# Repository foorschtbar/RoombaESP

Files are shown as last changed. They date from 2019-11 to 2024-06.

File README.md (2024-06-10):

# RoombaESP

This project is a Add-On PCB for the Roomba vacuum cleaner robots of series 500/600/700. It uses the open interface of the Roomba to control the robot via a ESP8266 microcontroller. The PCB is designed to be mounted on top in a 3D printed case and add

- MQTT
- REST API
- Monitoring Interface
- OLED Screen
- Status LED

## PCB

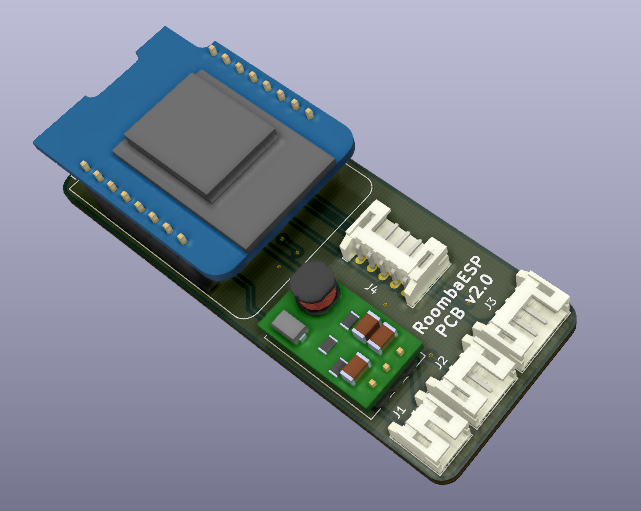
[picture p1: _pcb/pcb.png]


## Case & Features

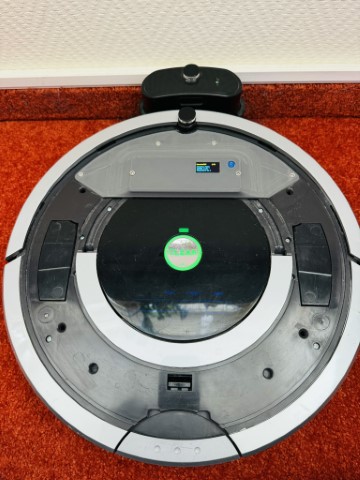
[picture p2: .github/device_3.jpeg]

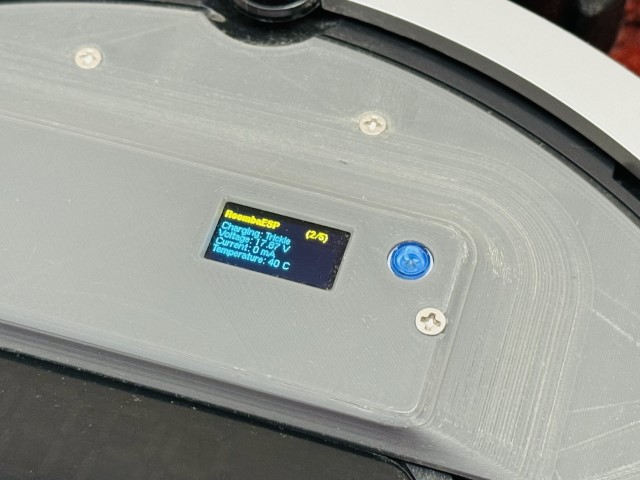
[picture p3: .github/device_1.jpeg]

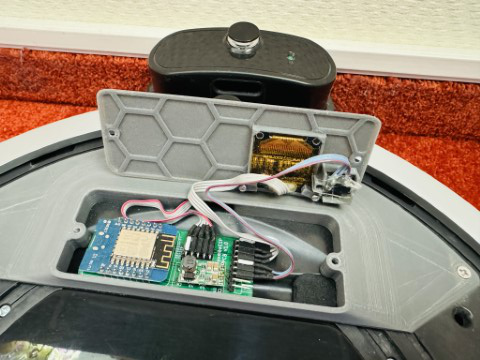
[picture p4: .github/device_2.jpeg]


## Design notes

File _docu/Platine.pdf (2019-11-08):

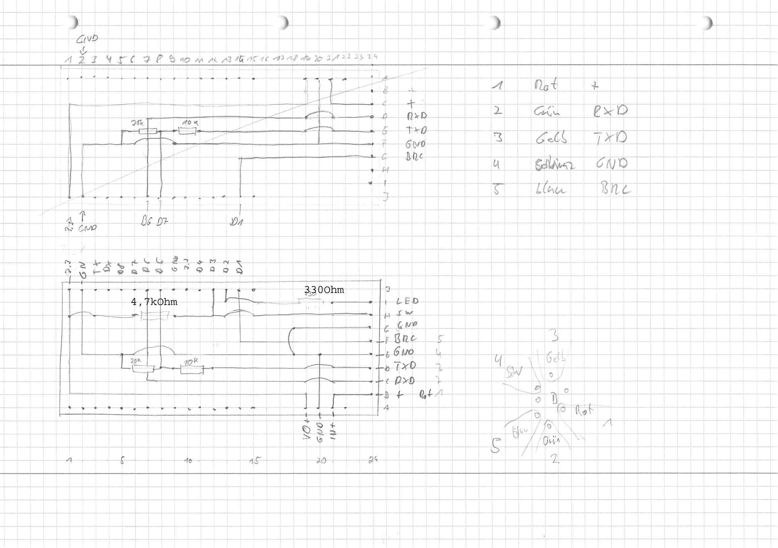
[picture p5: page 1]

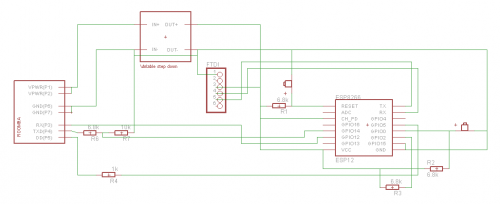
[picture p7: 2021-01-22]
_docu/R4_Circuit_Diag.png

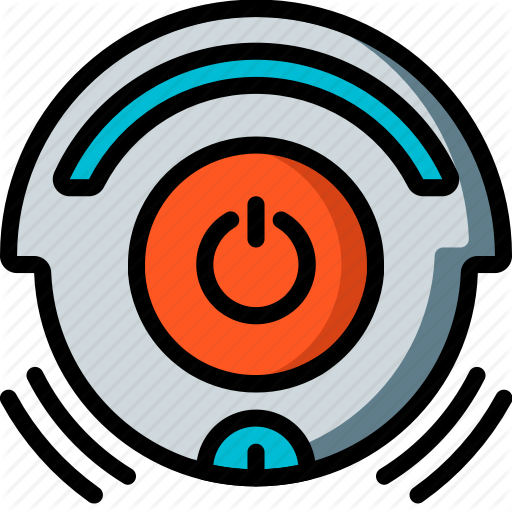
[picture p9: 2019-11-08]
_docu/Home_Automation_-_Ultra_-_049_-_Roomba_Off-512.png

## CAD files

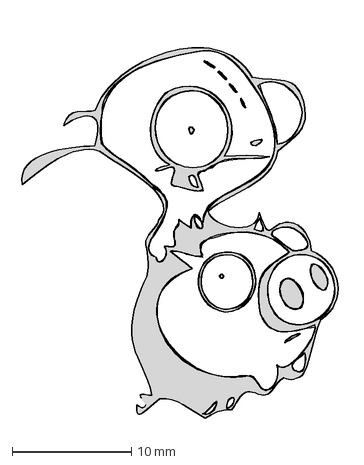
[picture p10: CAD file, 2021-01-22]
_pcb/invader zim flying pig_512.dxf
27.8 x 34.3 mm

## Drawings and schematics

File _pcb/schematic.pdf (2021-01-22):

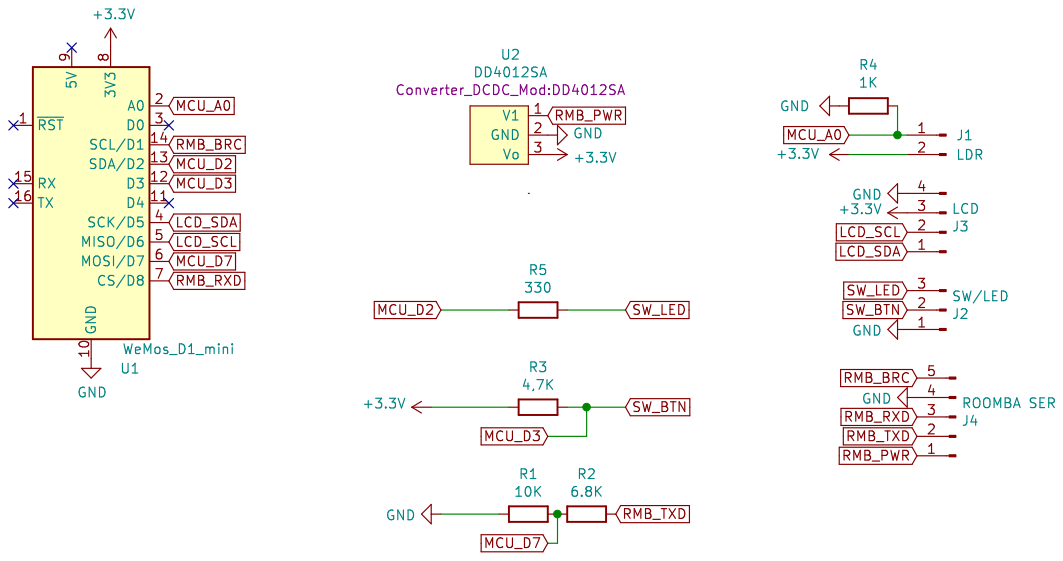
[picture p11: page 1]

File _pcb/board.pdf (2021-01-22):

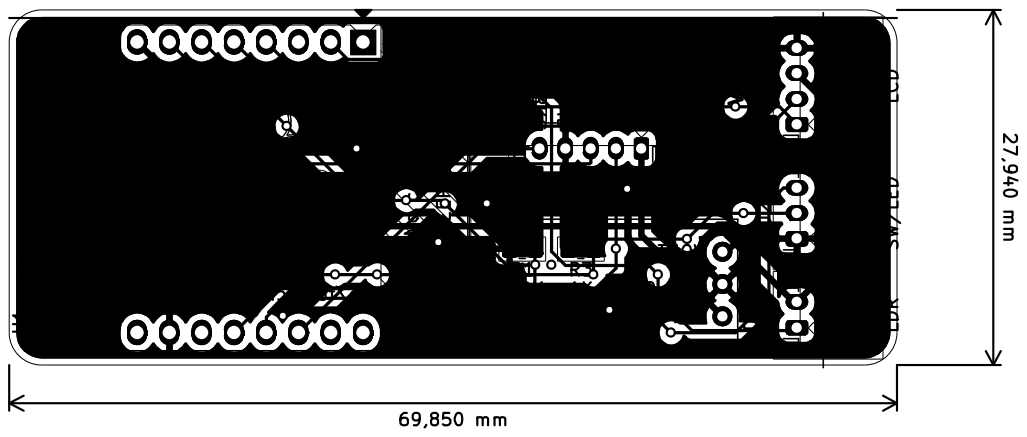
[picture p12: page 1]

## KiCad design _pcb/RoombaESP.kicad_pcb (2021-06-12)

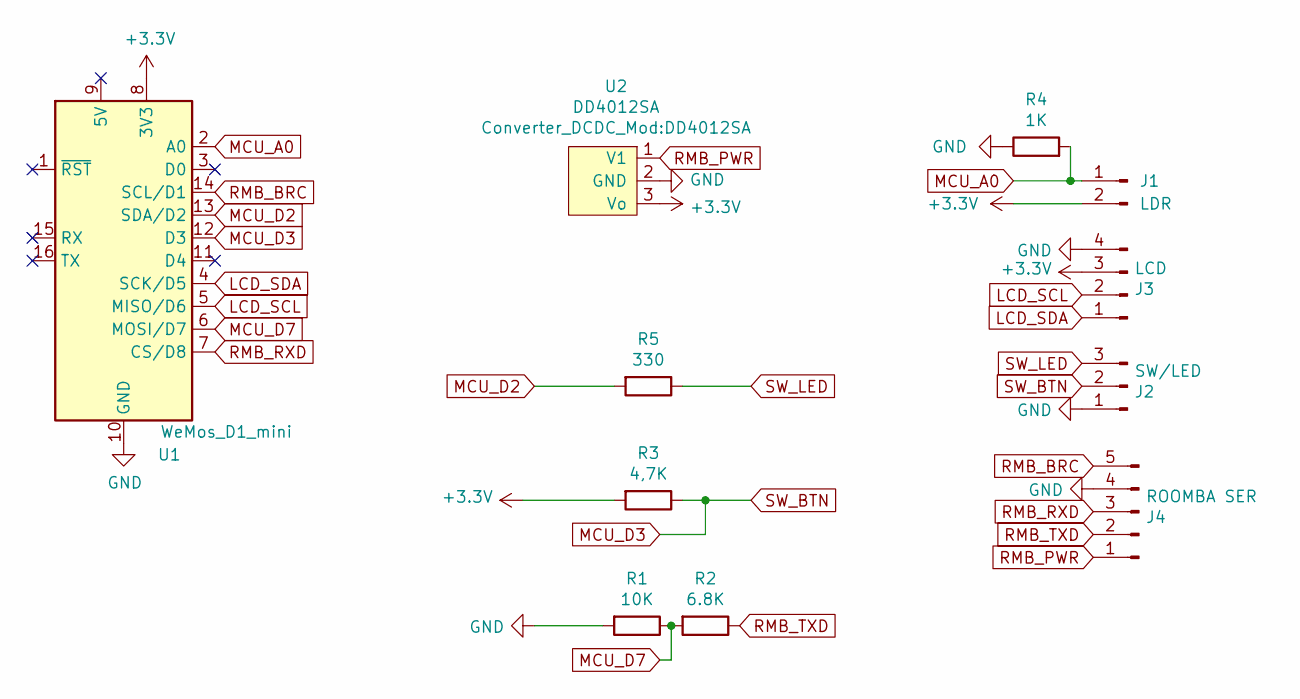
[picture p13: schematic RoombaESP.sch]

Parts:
J1: LDR; JST_PH_S2B-PH-K_1x02_P2.00mm_Horizontal
J2: SW/LED; JST_PH_S3B-PH-K_1x03_P2.00mm_Horizontal
J3: LCD; JST_PH_S4B-PH-K_1x04_P2.00mm_Horizontal
J4: ROOMBA SER; JST_PH_S5B-PH-K_1x05_P2.00mm_Horizontal
R1: 10K; R_0805_2012Metric_Pad1.20x1.40mm_HandSolder
R2: 6.8K; R_0805_2012Metric_Pad1.20x1.40mm_HandSolder
R3: 4,7K; R_0805_2012Metric_Pad1.20x1.40mm_HandSolder
R4: 1K; R_0805_2012Metric_Pad1.20x1.40mm_HandSolder
R5: 330; R_0805_2012Metric_Pad1.20x1.40mm_HandSolder
U1: WeMos_D1_mini; WEMOS_D1_mini_light
U2: DD4012SA

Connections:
+3V3: J1.2, J3.3, R3.2, U1.8 (3V3), U2.3 (Vo)
GND: J2.1, J3.4, J4.4, R1.2, R4.1, U1.10 (GND), U2.2 (GND)
LCD_SCL: J3.2, U1.5 (MISO/D6)
LCD_SDA: J3.1, U1.4 (SCK/D5)
MCU_A0: J1.1, R4.2, U1.2 (A0)
MCU_D2: R5.2, U1.13 (SDA/D2)
MCU_D3: J2.2, R3.1, U1.12 (D3)
MCU_D7: R1.1, R2.2, U1.6 (MOSI/D7)
RMB_BRC: J4.5, U1.14 (SCL/D1)
RMB_PWR: J4.1, U2.1 (V1)
RMB_RXD: J4.3, U1.7 (CS/D8)
RMB_TXD: J4.2, R2.1
SW_LED: J2.3, R5.1

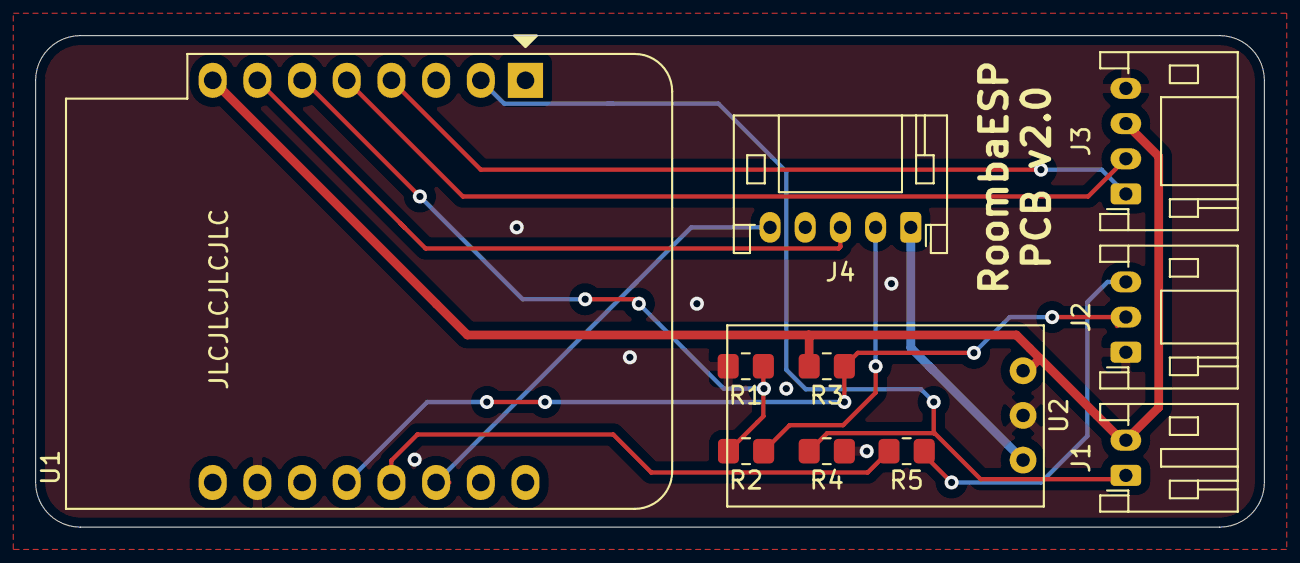
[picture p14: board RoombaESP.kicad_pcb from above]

Board: 2 copper layers, 69.9 x 27.9 mm, 11 parts (0 on the bottom side), 13 nets.

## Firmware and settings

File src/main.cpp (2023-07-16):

// Remote debug over telnet - not recommended for production, only for development
#include <RemoteDebug.h> //https://github.com/JoaoLopesF/RemoteDebug
#include <NTPClient.h>
#include <WiFiUdp.h> // needed by NTPClient.h
#include <ESP8266WiFi.h>
#include <WiFiClient.h>
#include <PubSubClient.h> // API Doc: https://pubsubclient.knolleary.net/api.html
#include <ArduinoJson.h>  // API Doc: https://arduinojson.org/v6/doc/
#include <ESP8266WebServer.h>
#include <ESP8266HTTPUpdateServer.h>
#include <EEPROM.h>
#include <U8g2lib.h>
#include <Wire.h>
#include <jled.h>
#include <Ticker.h>
#include <settings.h> // Include my type definitions (must be in a separate file!)
#include "screens.h"

// ++++++++++++++++++++++++++++++++++++++++
//
// DOCU
//
// ++++++++++++++++++++++++++++++++++++++++
/*
Serial (Swap)
http://arduino.esp8266.com/Arduino/versions/2.1.0-rc2/doc/reference.html#serial

https://dirtypcbs.com/store/designer/details/8372/892/roomba-4-zip

u8g2reference
https://github.com/olikraus/u8g2/wiki/u8g2reference
*/

// ++++++++++++++++++++++++++++++++++++++++
//
// CONSTANTS
//
// ++++++++++++++++++++++++++++++++++++++++

// Constants - HW pins
#define PIN_LED_WIFI D2 // Blue/Wifi LED (LED_BUILTIN=Nodemcu, D2 extern, D4=ESP-Chip-LED)
#define PIN_BRC D1
#define PIN_BUTTON D3

// Constants - Misc
const char FIRMWARE_VERSION[] = "2.2";
const char COMPILE_DATE[] = __DATE__ " " __TIME__;
const int PWMRANGE = 1023;

// Constants - Sensor
#define SENSORBYTES_LENGHT 10
unsigned long lastSensorStatusTime = 0;
char sensorbytes[SENSORBYTES_LENGHT];
boolean sensorbytesvalid = false;
#define CHARGE_STATE (int)(sensorbytes[0])
#define VOLTAGE (int)((sensorbytes[1] << 8) + sensorbytes[2])
#define CURRENT (signed short int)((sensorbytes[3] << 8) + sensorbytes[4])
#define TEMP (int)(sensorbytes[5])
#define CHARGE (int)((sensorbytes[6] << 8) + sensorbytes[7])
#define CAPACITY (int)((sensorbytes[8] << 8) + sensorbytes[9])

// Constants - Intervals (all in ms)
const int LED_FANCY_DURATION = 50; // interval at which to blink (milliseconds)
const int LED_WEB_MIN_TIME = 300;  // interval at which to blink (milliseconds)
const int TIME_BUTTON_LONGPRESS = 10000;
const long INTERVAL_SENSOR_STATUS = 1000;
const int STATE_PUBLISH_INTERVAL = 5000;
const int MQTT_RECONNECT_INTERVAL = 2000;
const int DISPLAY_UPDATE_INTERVAL = 200;
const int DISPLAY_TIMEOUT = 4000; // time after display will go offs

// Constants - MQTT
const char MQTT_SUBSCRIBE_CMD_TOPIC1[] = "%s/cmd";               // Subscribe patter without hostname
const char MQTT_SUBSCRIBE_CMD_TOPIC2[] = "%s%s/cmd";             // Subscribe patter with hostname
const char MQTT_PUBLISH_STATUS_TOPIC[] = "%s%s/status";          // Public pattern for status (normal and LWT) with hostname
const char MQTT_LWT_MESSAGE[] = "{\"device\":\"disconnected\"}"; // LWT message
const char MQTT_DEFAULT_PREFIX[] = "roombaesp";                  // Default MQTT topic prefix

// Constants - Screen (OLED)
const int SCREEN_COUNT = 5; // number of screens

// ++++++++++++++++++++++++++++++++++++++++
//
// ENUMS
//
// ++++++++++++++++++++++++++++++++++++++++

// Variables wont change
enum class RoombaCMDs
{
  RMB_WAKE,
  RMB_START,
  RMB_STOP,
  RMB_CLEAN,
  RMB_MAX,
  RMB_SPOT,
  RMB_DOCK,
  RMB_POWER,
  RMB_RESET
};

enum class StatusTrigger
{
  PERIODIC,
  WEB,
  MQTT,
  NONE // Triggers no update
};

// ++++++++++++++++++++++++++++++++++++++++
//
// LIBS
//
// ++++++++++++++++++++++++++++++++++++++++

ESP8266WebServer server(80);
ESP8266HTTPUpdateServer httpUpdater;
RemoteDebug Debug;
WiFiUDP ntpUDP;
NTPClient timeClient(ntpUDP, "europe.pool.ntp.org", 3600, 60000);
WiFiClient espClient;
PubSubClient client(espClient);
U8G2_SSD1306_128X64_NONAME_F_HW_I2C u8g2(U8G2_R0, /* reset=*/U8X8_PIN_NONE, /* clock=*/D6, /* data=*/D5); // pin remapping with ESP8266 HW I2C
Screens screen(u8g2, SCREEN_COUNT, DISPLAY_UPDATE_INTERVAL, DISPLAY_TIMEOUT);
Ticker ledTicker;
auto led = JLed(PIN_LED_WIFI);

// ++++++++++++++++++++++++++++++++++++++++
//
// VARS
//
// ++++++++++++++++++++++++++++++++++++++++

// Config
uint8_t cfgStart = 0;         // Start address in EEPROM for structure 'cfg'
configData_t cfg;             // Instance 'cfg' is a global variable with 'configData_t' structure now
bool configIsDefault = false; // true if no valid config found in eeprom and defaults settings loaded
const int CURRENT_CONFIG_VERSION = 2;

// Variables will change
int wifiledState = HIGH;
unsigned long lastLEDTime = 0;              // will store last time LED was updated
unsigned long lastButtonTimer = 0;          // will store how long button was pressed
unsigned long mqttLastReconnectAttempt = 0; // will store last time reconnect to mqtt broker
unsigned long nextPublishTime = 0;          // will store last publish time
unsigned long lastDisplayUpdate = 0;        // will store last display update
char mqtt_prefix[50];                       // prefix fpr mqtt topic
bool previousButtonState = 1;               // will store last Button state. 1 = unpressed, 0 = pressed
bool bIsConnected = false;
bool bMQTTsending = false;
int currentScreen = 0;
bool displayPowerSaving = true;
bool stopLEDupdate = false;
int ledBrightness = PWMRANGE;

// buffers
String html;
char buff[255];
char lastClean[50] = "---"; // will store last Clean

// function prototype
void HTMLHeader(const char *section, unsigned int refresh = 0, const char *url = "/");
void MQTTpublishStatus(StatusTrigger statusTrigger);
unsigned int getSensorStatus(bool force = false);

// ++++++++++++++++++++++++++++++++++++++++
//
// EVENT HANDLER
//
// ++++++++++++++++++++++++++++++++++++++++

WiFiEventHandler mConnectHandler;
WiFiEventHandler mDisConnectHandler;

// ++++++++++++++++++++++++++++++++++++++++
//
// MAIN CODE
//
// ++++++++++++++++++++++++++++++++++++++++

void clearSerialBuffer()
{
  while (Serial.available())
  {
    Serial.read();
  }
}

void saveConfig()
{
  EEPROM.begin(512);
  EEPROM.put(cfgStart, cfg);
  delay(200);
  EEPROM.commit(); // Only needed for ESP8266 to get data written
  EEPROM.end();
}

void eraseConfig()
{
  EEPROM.begin(512);
  for (uint8_t i = cfgStart; i < sizeof(cfg); i++)
  {
    EEPROM.write(i, 0);
  }
  delay(200);
  EEPROM.commit();
  EEPROM.end();
}

void handleButton()
{
  bool inp = digitalRead(PIN_BUTTON);
  if (inp == 0)
  {
    if (inp != previousButtonState)
    {
      rdebugA("Button pressed short\n");
      // ESP.reset();
      lastButtonTimer = millis();
      screen.nextScreen();
    }
    if ((millis() - lastButtonTimer >= TIME_BUTTON_LONGPRESS))
    {
      debugA("Button pressed long\n");
      eraseConfig();
      ESP.reset();
    }

    // Delay a little bit to avoid bouncing
    delay(50);
  }
  previousButtonState = inp;
}

void roombaCmd(RoombaCMDs cmd, StatusTrigger statusTrigger = StatusTrigger::NONE)
{

  switch (cmd)
  {
  case RoombaCMDs::RMB_WAKE:
    rdebugA("%s\n", "Send RMB_WAKE to RMB");
    digitalWrite(PIN_BRC, HIGH);
    delay(50);
    digitalWrite(PIN_BRC, LOW);
    delay(50);
    digitalWrite(PIN_BRC, HIGH);
    delay(50);
    digitalWrite(PIN_BRC, LOW);
    delay(50);
    break;

  case RoombaCMDs::RMB_START:
    rdebugA("%s\n", "Send RMB_START to RMB");
    Serial.write(128); // Start
    delay(50);
    break;

  case RoombaCMDs::RMB_STOP:
    roombaCmd(RoombaCMDs::RMB_WAKE);
    rdebugA("%s\n", "Send RMB_STOP to RMB");
    Serial.write(173); // Stop
    break;

  case RoombaCMDs::RMB_CLEAN:
    roombaCmd(RoombaCMDs::RMB_WAKE);
    roombaCmd(RoombaCMDs::RMB_START);
    rdebugA("%s\n", "Send RMB_CLEAN to RMB");
    Serial.write(135); // Clean
    break;

  case RoombaCMDs::RMB_MAX:
    roombaCmd(RoombaCMDs::RMB_WAKE);
    roombaCmd(RoombaCMDs::RMB_START);
    rdebugA("%s\n", "Send RMB_MAX to RMB");
    Serial.write(136); // Max
    break;

  case RoombaCMDs::RMB_SPOT:
    roombaCmd(RoombaCMDs::RMB_WAKE);
    roombaCmd(RoombaCMDs::RMB_START);
    rdebugA("%s\n", "Send RMB_SPOT to RMB");
    Serial.write(134); // Spot
    break;

  case RoombaCMDs::RMB_DOCK:
    roombaCmd(RoombaCMDs::RMB_WAKE);
    roombaCmd(RoombaCMDs::RMB_START);
    rdebugA("%s\n", "Send RMB_DOCK to RMB");
    Serial.write(143); // Seek Dock
    break;

  case RoombaCMDs::RMB_POWER:
    roombaCmd(RoombaCMDs::RMB_WAKE);
    roombaCmd(RoombaCMDs::RMB_START);
    rdebugA("%s\n", "Send RMB_POWER to RMB");
    Serial.write(133); // powers down Roomba
    break;

  case RoombaCMDs::RMB_RESET:
    roombaCmd(RoombaCMDs::RMB_WAKE);
    roombaCmd(RoombaCMDs::RMB_START);
    rdebugA("%s\n", "Send RMB_POWER to RMB");
    Serial.write(7); // resets down Roomba
    break;
  }

  if (statusTrigger != StatusTrigger::NONE)
  {
    delay(2000); // delay status message directly after command
    getSensorStatus(true);
    MQTTpublishStatus(statusTrigger);
  }
}

unsigned int getSensorStatus(bool force)
{
  unsigned long lastSensorStatusDiff = (millis() - lastSensorStatusTime);

  if (force || lastSensorStatusDiff >= INTERVAL_SENSOR_STATUS || lastSensorStatusTime == 0)
  {
    rdebugA("Get new sensor values\n");
    uint8_t i = 0;
    int8_t availabled = 0;

    clearSerialBuffer();

    yield();

    roombaCmd(RoombaCMDs::RMB_WAKE);
    roombaCmd(RoombaCMDs::RMB_START);

    Serial.write(142);
    Serial.write(3);
    delay(50);

    availabled = Serial.available();
    rdebugA("Bytes to read: %i\n", availabled);

    yield();

    if (availabled == SENSORBYTES_LENGHT)
    {
      while (Serial.available())
      {
        int c = Serial.read();

        if (i < SENSORBYTES_LENGHT)
        {
          sensorbytes[i++] = c;
        }
      }

      lastSensorStatusTime = millis();
      rdebugA("Successful read sensor status\n");
      sensorbytesvalid = true;
    }
    else
    {
      clearSerialBuffer();
      rdebugA("Error read sensor status. To less or many bytes. Expecting %d\n", SENSORBYTES_LENGHT);
      sensorbytesvalid = false;
    }

    yield();

    /*
    rdebugA("CHARGE_STATE: %i\n", CHARGE_STATE);
    rdebugA("VOLTAGE: %i\n", VOLTAGE);
    rdebugA("CURRENT: %i\n", CURRENT);
    rdebugA("TEMP: %i\n", TEMP);
    rdebugA("CHARGE: %i\n", CHARGE);
    rdebugA("CAPACITY: %i\n", CAPACITY);*/
    return availabled;
  }
  else
  {
    rdebugA("Use cached sensor values (next refresh in %lums)\n", ((INTERVAL_SENSOR_STATUS - lastSensorStatusDiff)));
  }

  return 0;
}

void showWEBMQTTAction(bool isWebAction = true)
{

  // Blink LED
  if (cfg.fancyled == 1)
  {
    // Turn of LED for a few milliseconds if access is from web or mqtt message is published
    stopLEDupdate = true;
    digitalWrite(PIN_LED_WIFI, LOW);
    ledTicker.attach_ms(LED_FANCY_DURATION, []()
                        { ledTicker.detach();
    led.Update();
    stopLEDupdate = false; });
  }
  else
  {
    analogWrite(PIN_LED_WIFI, ledBrightness);
    lastLEDTime = millis();
  }

  // Log Access to telnet
  if (isWebAction)
  {
    snprintf(buff, sizeof(buff), "%s %s %s ", server.client().remoteIP().toString().c_str(), (server.method() == HTTP_GET ? "GET" : "POST"), server.uri().c_str());

    // Log Access to telnet
    rdebugA("%s\n", buff);

    // Log Access to Logfile
    rdebugA("%s\n", buff);
  }
}

bool getRoombaSensorPacket(int PacketID, int &result)
{

  int low = 0;
  int high = 0;

  clearSerialBuffer();

  yield();

  roombaCmd(RoombaCMDs::RMB_WAKE);
  roombaCmd(RoombaCMDs::RMB_START);

  Serial.write(142);
  Serial.write(PacketID);
  delay(50);

  yield();

  if (Serial.available() > 0)
  {
    rdebugA("Bytes to read: %i\n", Serial.available());
    if (Serial.available() == 1)
    {
      sint8_t value = Serial.read();
      rdebugA("Serial.read: %i\n", value);
      rdebugA("Serial.read: %i\n", (signed int)value);
      rdebugA("Serial.read: %i\n", (unsigned int)value);
      rdebugA("Serial.read: %x\n", value);
      rdebugA("Serial.read: %i\n", value);
      rdebugA("Serial.read: %u\n", value);
      rdebugA("Serial.read: %i\n", (signed int)value);
      rdebugA("Serial.read: %u\n", (unsigned int)value);
      rdebugA("Serial.read: %u\n", (signed int)value);
      rdebugA("Serial.read: %u\n", (unsigned int)value);
      result = value;
      return true;
    }
    else if (Serial.available() == 2)
    {
      high = Serial.read();
      low = Serial.read();
      rdebugA("Serial.read: %i (%i, %i)\n", (high * 256 + low), high, low);
      rdebugA("Serial.read: %i, %i\n", lowByte(high * 256 + low), highByte(high * 256 + low));
      rdebugA("Serial.read: %i\n", (signed int)(low + (high << 8)));
      rdebugA("Serial.read: %i\n", (unsigned int)(low + (high << 8)));
      result = (high * 256 + low);
      return true;
    }
    else
    {
      while (Serial.available())
      {
        rdebugA("%i\n", Serial.read());
      }
    }
  }
  else
  {
    rdebugA("Es gibt nichts zu lesen! %s\n", "");
    return false;
  }

  return false;
}

bool isRoombaCleaning()
{
  getSensorStatus();
  if (CHARGE_STATE == 1 || CHARGE_STATE == 2 || CHARGE_STATE == 3 || CHARGE_STATE == 5 || !sensorbytesvalid)
  {
    return false;
  }
  else
  {
    if (CURRENT < -400)
    {
      return true;
    }
    else
    {
      return false;
    }
  }
}

bool isRoombaCharging()
{
  getSensorStatus();
  if (sensorbytesvalid && (CHARGE_STATE == 1 || CHARGE_STATE == 2 || CHARGE_STATE == 3 || CHARGE_STATE == 5))
  {
    return true;
  }
  else
  {
    return false;
  }
}

String getStatusTriggerString(StatusTrigger statusTrigger)
{
  switch (statusTrigger)
  {
  case StatusTrigger::PERIODIC:
    return "periodic";
    break;
  case StatusTrigger::WEB:
    return "web";
    break;
  case StatusTrigger::MQTT:
    return "mqtt";
    break;
  case StatusTrigger::NONE:
    return "none";
    break;
  default:
    return "unknown";
    break;
  }
}

void MQTTpublishStatus(StatusTrigger statusTrigger)
{
  char jsonpretty[255];
  showWEBMQTTAction(false);
  rdebugA("Publish MQTT status message\n");
  uint16_t mqtt_buffersize = client.getBufferSize();

  char payload[mqtt_buffersize];
  DynamicJsonDocument jsondoc(mqtt_buffersize);

  // getSensorStatus(true);
  jsondoc["cleaning"] = isRoombaCleaning();
  jsondoc["charging"] = isRoombaCharging();
  jsondoc["trigger"] = getStatusTriggerString(statusTrigger);
  jsondoc["note"] = cfg.note;
  jsondoc["firmware"] = FIRMWARE_VERSION;
  jsondoc["wifi_rssi"] = WiFi.RSSI();

  size_t payloadSize = serializeJson(jsondoc, payload, sizeof(payload));
  serializeJsonPretty(jsondoc, jsonpretty, sizeof(jsonpretty));

  snprintf(buff, sizeof(buff), MQTT_PUBLISH_STATUS_TOPIC, mqtt_prefix, cfg.mqtt_prefix);

  rdebugA("Payload-/Buffersize: %i/%i bytes (%i%%)\n", payloadSize, mqtt_buffersize, (int)((100.00 / (double)mqtt_buffersize) * payloadSize));
  rdebugA("Topic: %s\nMessage: %s\n", buff, jsonpretty);

  if (!client.publish(buff, (uint8_t *)payload, (unsigned int)payloadSize, true))
  {
    rdebugAln("Failed to publish message!");
  }

  nextPublishTime = millis() + (cfg.mqtt_periodic_update_interval * 1000);
}

long RSSI2Quality(long dBm)
{
  if (dBm <= -100)
    return 0;
  else if (dBm >= -50)
    return 100;
  else
    return 2 * (dBm + 100);
}

void loadDefaults()
{
  String TmpStr = "";

  // Config NOT from EEPROM
  configIsDefault = true;

  // Valid-Falg to verify config
  cfg.configisvalid = CURRENT_CONFIG_VERSION;

  memcpy(cfg.wifi_ssid, "", sizeof(cfg.wifi_ssid) / sizeof(*cfg.wifi_ssid));
  memcpy(cfg.wifi_psk, "", sizeof(cfg.wifi_psk) / sizeof(*cfg.wifi_psk));

  memcpy(cfg.hostname, "", sizeof(cfg.hostname) / sizeof(*cfg.hostname));
  memcpy(cfg.note, "", sizeof(cfg.note) / sizeof(*cfg.note));

  memcpy(cfg.admin_username, "", sizeof(cfg.admin_username) / sizeof(*cfg.admin_username));
  memcpy(cfg.admin_password, "", sizeof(cfg.admin_password) / sizeof(*cfg.admin_password));

  memcpy(cfg.api_username, "", sizeof(cfg.api_username) / sizeof(*cfg.api_username)); // Legancy setting
  memcpy(cfg.api_password, "", sizeof(cfg.api_password) / sizeof(*cfg.api_password)); // Legancy setting

  cfg.telnet = 0;

  memcpy(cfg.mqtt_server, "", sizeof(cfg.mqtt_server) / sizeof(*cfg.mqtt_server));
  memcpy(cfg.mqtt_user, "", sizeof(cfg.mqtt_user) / sizeof(*cfg.mqtt_user));
  cfg.mqtt_port = 1883;
  memcpy(cfg.mqtt_password, "", sizeof(cfg.mqtt_password) / sizeof(*cfg.mqtt_password));
  memcpy(cfg.mqtt_prefix, MQTT_DEFAULT_PREFIX, sizeof(cfg.mqtt_prefix) / sizeof(*cfg.mqtt_prefix));
  cfg.mqtt_periodic_update_interval = 10;

  cfg.fancyled = 0;
  cfg.led_brightness = 50;
}

void loadConfig()
{
  EEPROM.begin(512);
  EEPROM.get(cfgStart, cfg);
  EEPROM.end();

  if (cfg.configisvalid != CURRENT_CONFIG_VERSION)
  {
    loadDefaults();
  }
  else
  {
    configIsDefault = false; // Config from EEPROM
  }
}

String chargeStateString()
{
  if (sensorbytesvalid)
  {
    switch (CHARGE_STATE)
    {
    case 0:
      return "Not charging";
      break;
    case 1:
      return "Reconditioning";
      break;
    case 2:
      return "Full";
      break;
    case 3:
      return "Trickle";
      break;
    case 4:
      return "Waiting";
      break;
    case 5:
      return "Fault Condition";
      break;
    }
  }

  return "Charging Unknown";
}
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
void loop(void)
{
  // Update LEDs
  if (cfg.fancyled == 1)
  {
    // LED
    if (!stopLEDupdate)
    {
      led.Update();
    }
  }
  else
  {
    // showWEBMQTTAction
    if (millis() - lastLEDTime >= LED_WEB_MIN_TIME)
    {
      analogWrite(PIN_LED_WIFI, 0);
    }
  }

  // Button
  handleButton();

  // Webserver
  server.handleClient();

  // Display
  screen.loop();
  handleDisplay();

  // handle if we have a wifi connection (to wifi station)
  if (WiFi.status() == WL_CONNECTED)
  {
    // Remote Debug
    if (cfg.telnet)
    {
      Debug.handle();
    }

    // NTPClient Update
    timeClient.update();

    // MQTT - if config valid
    if (!configIsDefault)
    {

      if (!client.connected())
      {
        // MQTT connect
        if (mqttLastReconnectAttempt == 0 || (millis() - mqttLastReconnectAttempt) >= MQTT_RECONNECT_INTERVAL)
        {
          mqttLastReconnectAttempt = millis();

          // try to reconnect
          if (MQTTreconnect())
          {
            mqttLastReconnectAttempt = 0;
          }
        }
      }
      else
      {
        // Handle MQTT msgs
        client.loop();

        // send periodic update if enabled
        if (cfg.mqtt_periodic_update_interval > 0)
        {
          if (millis() >= nextPublishTime)
          {
            MQTTpublishStatus(StatusTrigger::PERIODIC);
          }
        }
      }
    }
  }
}

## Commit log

2019-11-19 Fix sensor status problem with some yield()'s
    [main.cpp]
2021-01-17 Added Screen Switching and Timeout
2021-01-19 Some improvments - added more screens - fix some issues with mqtt topics - add a lot of debug output to telnet - cleanup code
    [main.cpp]
2021-01-22 Added KiCad PCB v1.0
    [RoombaESP.kicad_pcb, RoombaESP.sch, invader zim flying pig_512.dxf]
2021-01-22 Added RoombaESP PCB v2.0
    [RoombaESP.sch]
2021-01-22 Added README and PCB image
2021-05-22 Added Gerber files
2021-06-12 Updated PCB
    [RoombaESP.kicad_pcb]
2023-05-26 Added fancy led animation
2023-07-16 Make fancy led configurable
